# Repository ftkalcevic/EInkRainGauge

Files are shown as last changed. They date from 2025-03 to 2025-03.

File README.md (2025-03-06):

# Digital Rain Gauge with battery, solar panel and eink display

This project is a digital rain gauge that uses a tipping bucket mechanism to measure the amount of rain that has fallen. The rain gauge is powered by a battery and a solar panel and displays the amount of rain that has fallen on an eink display.

Note - the project details are not complete instructions.  I often uses scrap box parts, or parts I get from my local electronics store.  This is more of a guide to show what I did.

## Hardware

The hardware used in this project is as follows:

- STM32F103 microcontroller (initially developed with a blue pill board, then a custom board was created with only the required components).
- DFROBOT Micro Solar Power Manager / Charger with Regulated Output (DFR0579).
- Waveshare 250x122, 2.13inch E-Ink display HAT for Raspberry Pi (12915) - the one with the 8 pin connector.
- 500mAh LiPo battery.
- Reed switch to sense the rain bucket tipping.
- UV safe cover over the eink display (although the display faces away from the sun, it is unclear how the eink display works outside, so it is protected by a UV safe piece of perspex)

## Software

The files are in RainGaugeDigital.  I use VisualGDB hosted in Visual Studio.

The program spends most of its time in low power mode.  It will wake when the button tips (reed switch), or when one of the UI buttons is pressed.

The STM32F103 doesn't have any permanent storage, eg EEPROM.  The data collected is stored in ram.  If the battery is removed, the data is lost.

The display showing the mm of rain is not updated until 1 minute after the first tip.  This is to reduce power use.

The DFROBOT Micro Solar Power Manager can harvest very low voltages to charge the battery.  The built in voltage regulator powers the circuit at 3.3V.

The eink display code is based on the samples in the wiki.  A few changes were made to the code more flexible, and increase performance by using DMA transfers.

## Schematic

Files and a PDF schematic are in the EInkRainGaugePCB folder.  I use CircuitStudio.

## 3D Printed Parts

Alibre Design files are in the 3dModel\Alibre folder.  Step files in the 3dModel\Step folder.  Stl files in the 3dModel\Stl folder.

Note - not many fastners are shown in the 3D model.  I used M3 screws and heat set inserts.

The catchment funnel has 10 holes around the topmost edge to install 20cm 0.8mm spring steel (piano wire) pieces to discourage birds from perching on the funnel.

This is a 3d render of the model:
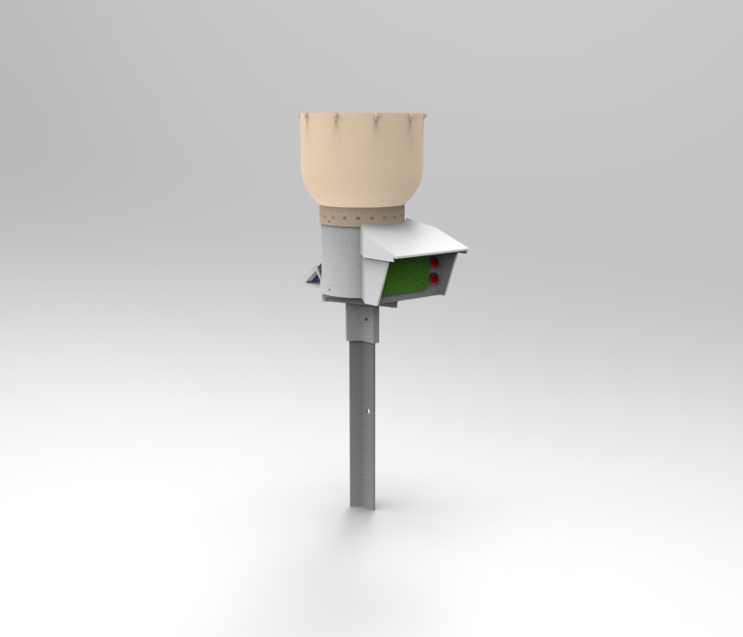
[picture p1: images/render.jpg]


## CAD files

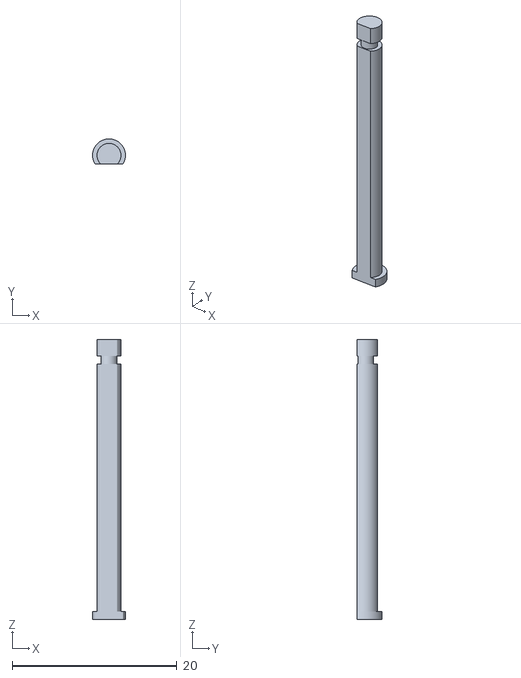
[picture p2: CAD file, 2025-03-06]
3dModel/stl/pin1.stl
4.00 x 3.06 x 34.0

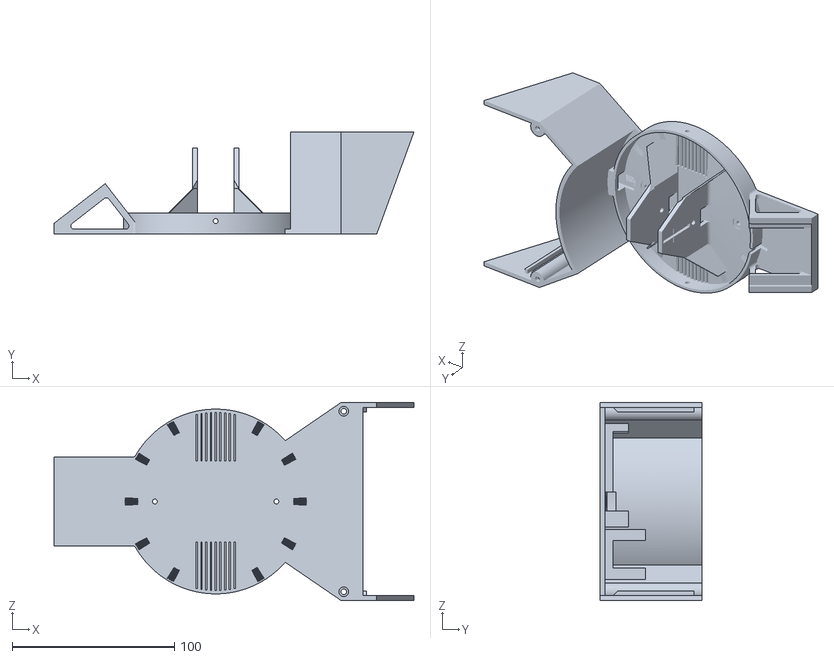
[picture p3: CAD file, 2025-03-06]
3dModel/stl/base.stl
222.2 x 63.0 x 122.2

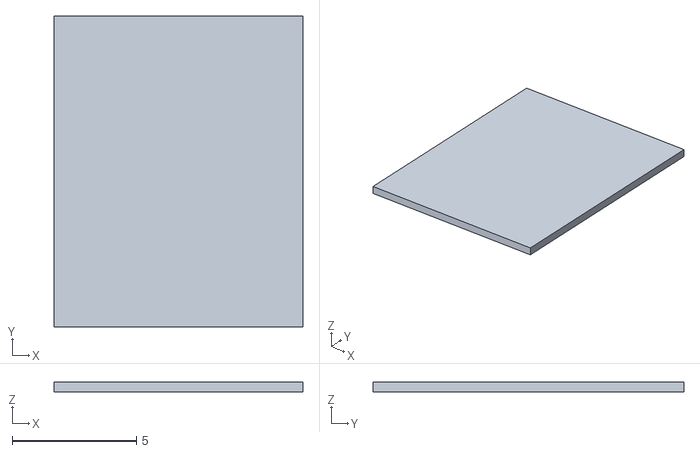
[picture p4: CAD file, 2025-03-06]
3dModel/stl/drip tab.stl
10.0 x 12.5 x 0.4

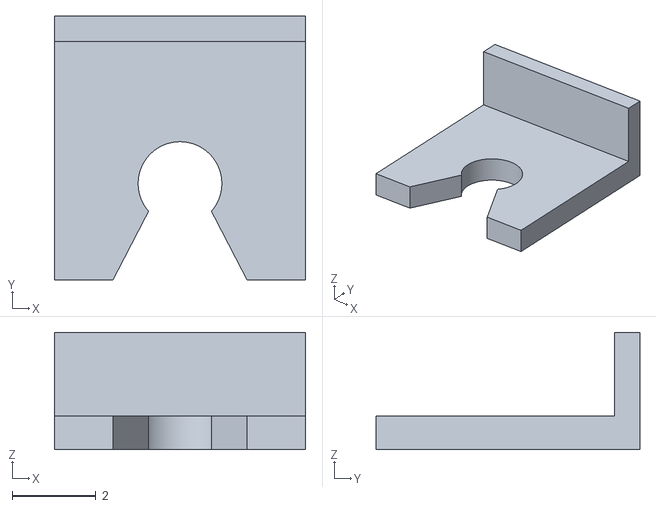
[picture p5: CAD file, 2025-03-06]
3dModel/stl/PinClip.stl
6.00 x 6.30 x 2.80

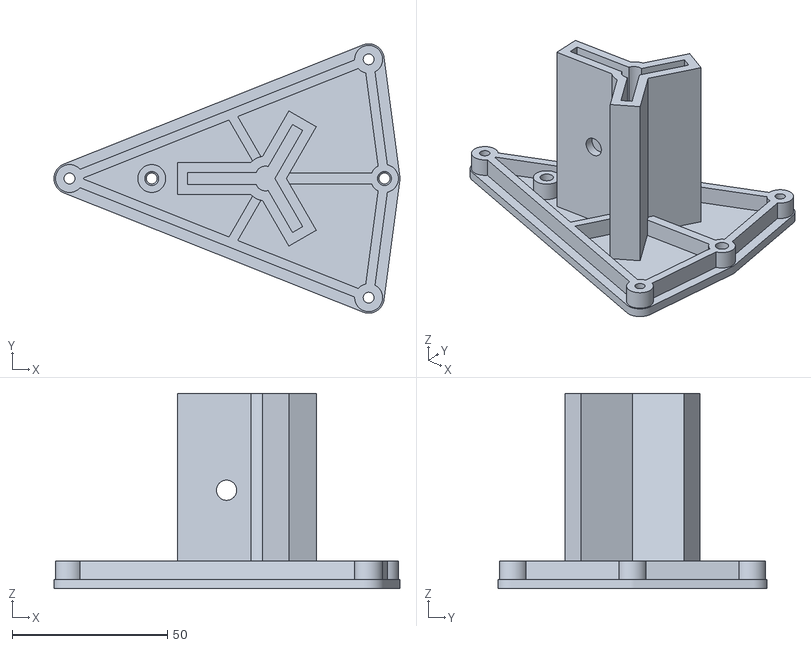
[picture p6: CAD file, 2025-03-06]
3dModel/stl/star picket leveling mount.stl
111.5 x 86.8 x 63.0

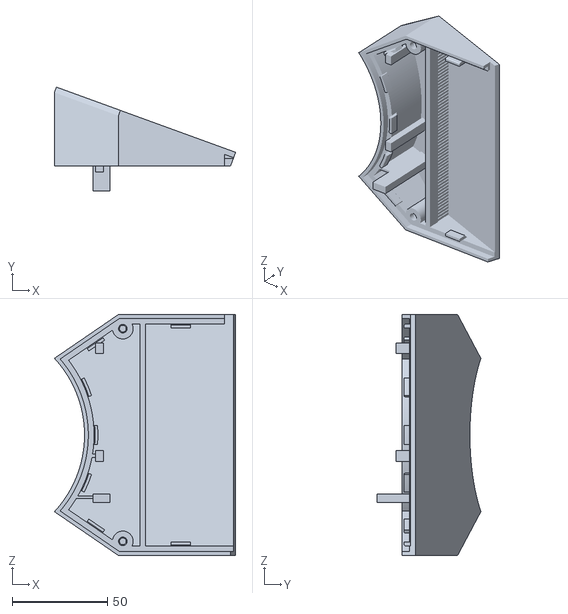
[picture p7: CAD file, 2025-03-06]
3dModel/stl/DisplayRoof.stl
94.9 x 54.4 x 126.2

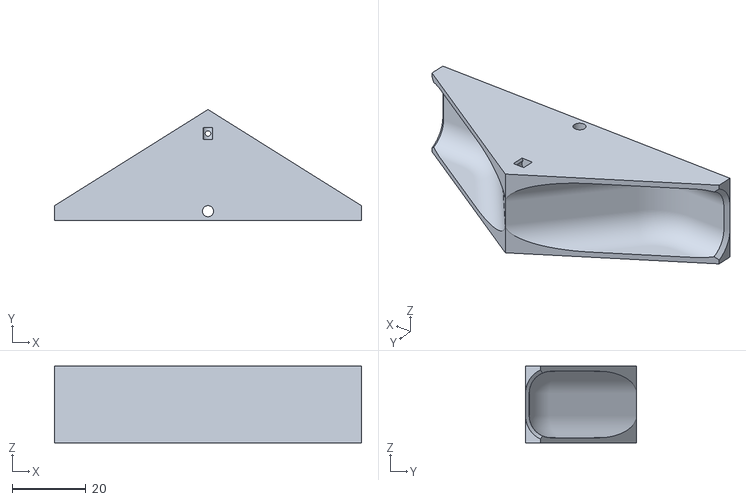
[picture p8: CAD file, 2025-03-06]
3dModel/stl/bucket2.stl
83.0 x 30.0 x 20.7

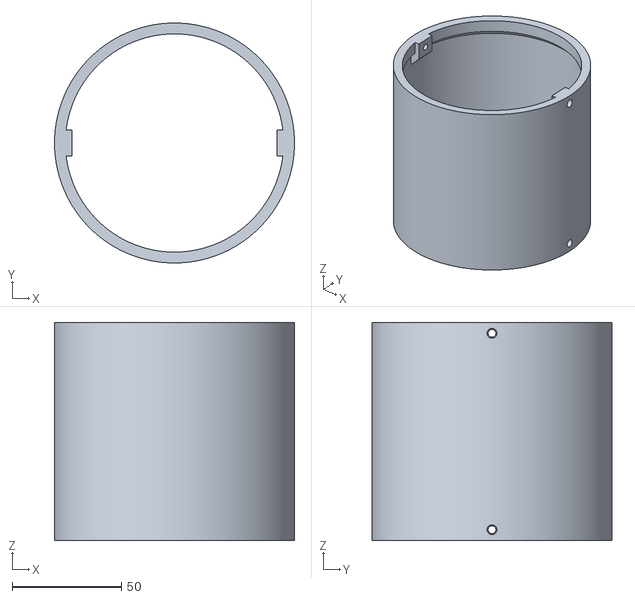
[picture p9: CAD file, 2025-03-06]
3dModel/stl/pipe.stl
110.0 x 110.0 x 100.0

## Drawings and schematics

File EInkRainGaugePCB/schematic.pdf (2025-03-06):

# P1 SWD RST SWDIO

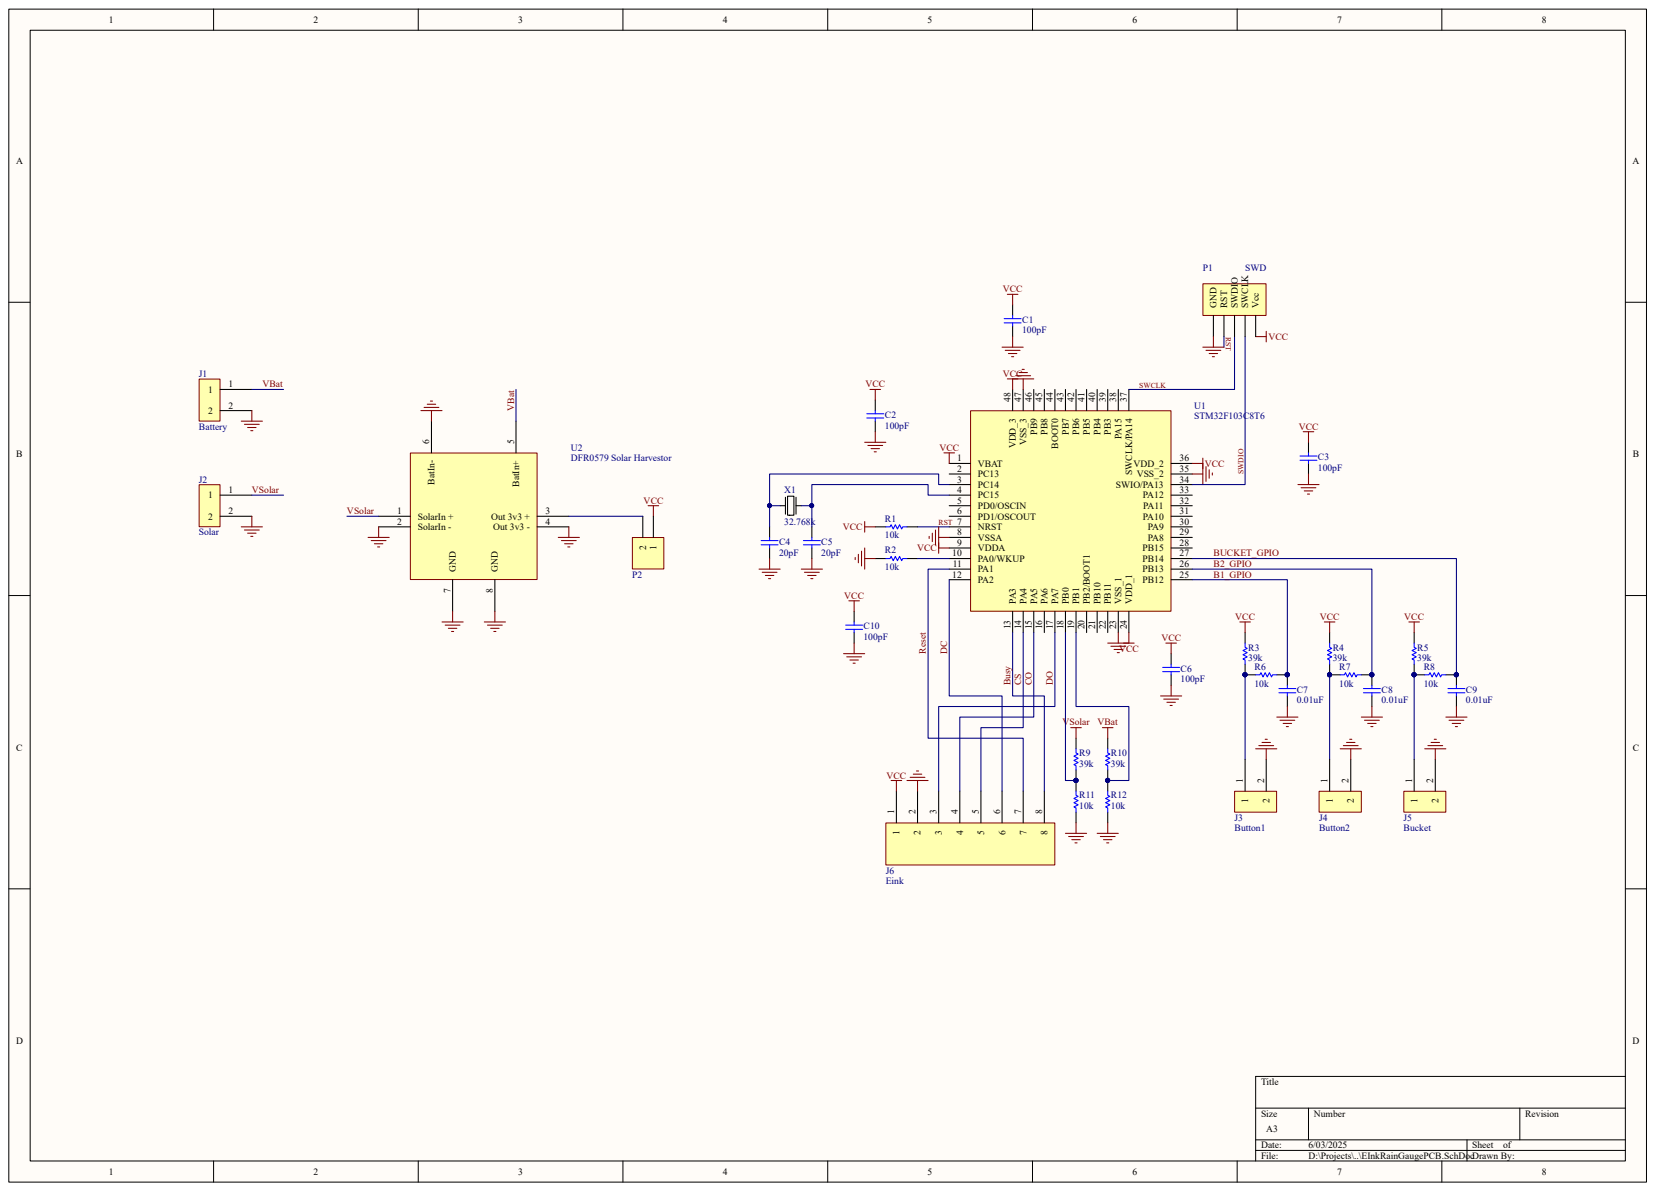
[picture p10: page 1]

VCC GND RST SWDIO SWCLK Vcc

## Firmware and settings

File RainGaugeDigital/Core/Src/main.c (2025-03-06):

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
/* Includes ------------------------------------------------------------------*/
#include "main.h"

/* USER CODE BEGIN Includes */
#include "../../RainGaugeApp.h"
#include <stdio.h>
#include "../../Debug.h"
/* USER CODE END Includes */

ADC_HandleTypeDef hadc1;

RTC_HandleTypeDef hrtc;

SPI_HandleTypeDef hspi1;
DMA_HandleTypeDef hdma_spi1_tx;

void SystemClock_Config(void);
static void MX_GPIO_Init(void);
static void MX_DMA_Init(void);
static void MX_ADC1_Init(void);
static void MX_RTC_Init(void);
static void MX_SPI1_Init(void);
/* USER CODE BEGIN 0 */
/// @brief  Possible STM32 system reset causes
typedef enum reset_cause_e
{
	RESET_CAUSE_UNKNOWN                    = 0,
	RESET_CAUSE_LOW_POWER_RESET,
	RESET_CAUSE_WINDOW_WATCHDOG_RESET,
	RESET_CAUSE_INDEPENDENT_WATCHDOG_RESET,
	RESET_CAUSE_SOFTWARE_RESET,
	RESET_CAUSE_POWER_ON_POWER_DOWN_RESET,
	RESET_CAUSE_EXTERNAL_RESET_PIN_RESET,
	RESET_CAUSE_BROWNOUT_RESET,
} reset_cause_t;

/// @brief      Obtain the STM32 system reset cause
/// @param      None
/// @return     The system reset cause
reset_cause_t reset_cause_get(void)
{
	reset_cause_t reset_cause;

	if (__HAL_RCC_GET_FLAG(RCC_FLAG_LPWRRST))
	{
		reset_cause = RESET_CAUSE_LOW_POWER_RESET;
	}
	else if (__HAL_RCC_GET_FLAG(RCC_FLAG_WWDGRST))
	{
		reset_cause = RESET_CAUSE_WINDOW_WATCHDOG_RESET;
	}
	else if (__HAL_RCC_GET_FLAG(RCC_FLAG_IWDGRST))
	{
		reset_cause = RESET_CAUSE_INDEPENDENT_WATCHDOG_RESET;
	}
	else if (__HAL_RCC_GET_FLAG(RCC_FLAG_SFTRST))
	{
		// This reset is induced by calling the ARM CMSIS 
		// `NVIC_SystemReset()` function!
		reset_cause = RESET_CAUSE_SOFTWARE_RESET; 
	}
	else if (__HAL_RCC_GET_FLAG(RCC_FLAG_PORRST))
	{
		reset_cause = RESET_CAUSE_POWER_ON_POWER_DOWN_RESET;
	}
	else if (__HAL_RCC_GET_FLAG(RCC_FLAG_PINRST))
	{
		reset_cause = RESET_CAUSE_EXTERNAL_RESET_PIN_RESET;
	}
	// Needs to come *after* checking the `RCC_FLAG_PORRST` flag in order to
	// ensure first that the reset cause is NOT a POR/PDR reset. See note
	// below. 
	//else if (__HAL_RCC_GET_FLAG(RCC_FLAG_BORRST))
	//{
	//	reset_cause = RESET_CAUSE_BROWNOUT_RESET;
	//}
	else
	{
		reset_cause = RESET_CAUSE_UNKNOWN;
	}

	// Clear all the reset flags or else they will remain set during future
	// resets until system power is fully removed.
	__HAL_RCC_CLEAR_RESET_FLAGS();

	return reset_cause; 
}

// Note: any of the STM32 Hardware Abstraction Layer (HAL) Reset and Clock
// Controller (RCC) header files, such as 
// "STM32Cube_FW_F7_V1.12.0/Drivers/STM32F7xx_HAL_Driver/Inc/stm32f7xx_hal_rcc.h",
// "STM32Cube_FW_F2_V1.7.0/Drivers/STM32F2xx_HAL_Driver/Inc/stm32f2xx_hal_rcc.h",
// etc., indicate that the brownout flag, `RCC_FLAG_BORRST`, will be set in
// the event of a "POR/PDR or BOR reset". This means that a Power-On Reset
// (POR), Power-Down Reset (PDR), OR Brownout Reset (BOR) will trip this flag.
// See the doxygen just above their definition for the 
// `__HAL_RCC_GET_FLAG()` macro to see this:
//      "@arg RCC_FLAG_BORRST: POR/PDR or BOR reset." <== indicates the Brownout
//      Reset flag will *also* be set in the event of a POR/PDR. 
// Therefore, you must check the Brownout Reset flag, `RCC_FLAG_BORRST`, *after*
// first checking the `RCC_FLAG_PORRST` flag in order to ensure first that the
// reset cause is NOT a POR/PDR reset.


/// @brief      Obtain the system reset cause as an ASCII-printable name string 
///             from a reset cause type
/// @param[in]  reset_cause     The previously-obtained system reset cause
/// @return     A null-terminated ASCII name string describing the system 
///             reset cause
const char * reset_cause_get_name(reset_cause_t reset_cause)
{
	const char * reset_cause_name = "TBD";

	switch (reset_cause)
	{
	case RESET_CAUSE_UNKNOWN:
		reset_cause_name = "UNKNOWN";
		break;
	case RESET_CAUSE_LOW_POWER_RESET:
		reset_cause_name = "LOW_POWER_RESET";
		break;
	case RESET_CAUSE_WINDOW_WATCHDOG_RESET:
		reset_cause_name = "WINDOW_WATCHDOG_RESET";
		break;
	case RESET_CAUSE_INDEPENDENT_WATCHDOG_RESET:
		reset_cause_name = "INDEPENDENT_WATCHDOG_RESET";
		break;
	case RESET_CAUSE_SOFTWARE_RESET:
		reset_cause_name = "SOFTWARE_RESET";
		break;
	case RESET_CAUSE_POWER_ON_POWER_DOWN_RESET:
		reset_cause_name = "POWER-ON_RESET (POR) / POWER-DOWN_RESET (PDR)";
		break;
	case RESET_CAUSE_EXTERNAL_RESET_PIN_RESET:
		reset_cause_name = "EXTERNAL_RESET_PIN_RESET";
		break;
	case RESET_CAUSE_BROWNOUT_RESET:
		reset_cause_name = "BROWNOUT_RESET (BOR)";
		break;
	}

	return reset_cause_name;
}
/* USER CODE END 0 */

/**
  * @brief  The application entry point.
  * @retval int
  */
int main(void)
{
  /* USER CODE BEGIN 1 */
  reset_cause_t reset_cause = reset_cause_get();
  /* USER CODE END 1 */

  /* MCU Configuration--------------------------------------------------------*/

  /* Reset of all peripherals, Initializes the Flash interface and the Systick. */
  HAL_Init();

  /* Configure the system clock */
  SystemClock_Config();

  /* Initialize all configured peripherals */
  MX_GPIO_Init();
  MX_DMA_Init();
  MX_ADC1_Init();
  MX_RTC_Init();
  MX_SPI1_Init();
  /* USER CODE BEGIN 2 */
#define SET_DATETIME_ON_START 
#ifdef SET_DATETIME_ON_START
	const uint8_t compileYear = (__DATE__[9] - '0') * 10 + (__DATE__[10] - '0');
	const uint8_t compileMonth = (__DATE__[0] == 'J') ? ((__DATE__[1] == 'a') ? 1 : ((__DATE__[2] == 'n') ? 6 : 7))    // Jan, Jun or Jul
										: (__DATE__[0] == 'F') ? 2                                                              // Feb
										: (__DATE__[0] == 'M') ? ((__DATE__[2] == 'r') ? 3 : 5)                                 // Mar or May
										: (__DATE__[0] == 'A') ? ((__DATE__[1] == 'p') ? 4 : 8)                                 // Apr or Aug
										: (__DATE__[0] == 'S') ? 9                                                              // Sep
										: (__DATE__[0] == 'O') ? 10                                                             // Oct
										: (__DATE__[0] == 'N') ? 11                                                             // Nov
										: (__DATE__[0] == 'D') ? 12                                                             // Dec
										: 0;
	const uint8_t compileDay = (__DATE__[4] == ' ') ? (__DATE__[5] - '0') : (__DATE__[4] - '0') * 10 + (__DATE__[5] - '0');
	
	const uint8_t compileHour = (__TIME__[0] == ' ') ? (__TIME__[1] - '0') : (__TIME__[0] - '0') * 10 + (__TIME__[1] - '0');
	const uint8_t compileMinute = (__TIME__[3] - '0') * 10 + (__TIME__[4] - '0');
	const uint8_t compileSecond = (__TIME__[6] - '0') * 10 + (__TIME__[7] - '0');

	RTC_TimeTypeDef time;
	time.Hours = compileHour;
	time.Minutes = compileMinute;
	time.Seconds = compileSecond;
	HAL_RTC_SetTime(&hrtc, &time, RTC_FORMAT_BIN);
	
	RTC_DateTypeDef date;
	date.Date = compileDay;
	date.Month = compileMonth;
	date.Year = compileYear;
	HAL_RTC_SetDate(&hrtc, &date, RTC_FORMAT_BIN);	 
#endif	
	{
		// EXTI configuration
		/*
		EXTI_HandleTypeDef hexti;
		HAL_EXTI_GetHandle(&hexti, EXTI_LINE_17);
		EXTI_ConfigTypeDef hexti_config;
		HAL_EXTI_GetConfigLine(&hexti, &hexti_config);
		HAL_EXTI_ClearPending(&hexti, EXTI_TRIGGER_RISING_FALLING);
		hexti_config.Line = EXTI_LINE_17;
		hexti_config.Mode = EXTI_MODE_INTERRUPT;
		hexti_config.Trigger = EXTI_TRIGGER_RISING;
		HAL_EXTI_SetConfigLine(&hexti, &hexti_config);
		*/
	}

  /* USER CODE END 2 */

  /* Infinite loop */
  /* USER CODE BEGIN WHILE */
  while (1)
  {
    /* USER CODE END WHILE */

    /* USER CODE BEGIN 3 */
	  Debug("The system reset cause is \"%s\"\n", reset_cause_get_name(reset_cause));
	  Debug("Delaying 5sec\n");
	  //HAL_Delay(5000);
	  Debug("Starting\n");
	  rain_guage_app();
  }
  /* USER CODE END 3 */
}

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


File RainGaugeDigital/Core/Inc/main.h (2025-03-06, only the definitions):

#define GPIO_EINK_Reset_Pin GPIO_PIN_1
#define GPIO_EINK_Reset_GPIO_Port GPIOA
#define GPIO_EINK_DC_Pin GPIO_PIN_2
#define GPIO_EINK_DC_GPIO_Port GPIOA
#define GPIO_EINK_Busy_Pin GPIO_PIN_3
#define GPIO_EINK_Busy_GPIO_Port GPIOA
#define SPI_EINK_CS_Pin GPIO_PIN_4
#define SPI_EINK_CS_GPIO_Port GPIOA
#define SPI_EINK_CO_Pin GPIO_PIN_5
#define SPI_EINK_CO_GPIO_Port GPIOA
#define SPI_EINK_DO_Pin GPIO_PIN_7
#define SPI_EINK_DO_GPIO_Port GPIOA
#define ADC1_VSOLAR_Pin GPIO_PIN_0
#define ADC1_VSOLAR_GPIO_Port GPIOB
#define ADC1_VBAT_Pin GPIO_PIN_1
#define ADC1_VBAT_GPIO_Port GPIOB
#define GPIO_BUTTON1_Pin GPIO_PIN_12
#define GPIO_BUTTON1_GPIO_Port GPIOB
#define GPIO_BUTTON1_EXTI_IRQn EXTI15_10_IRQn
#define GPIO_BUTTON2_Pin GPIO_PIN_13
#define GPIO_BUTTON2_GPIO_Port GPIOB
#define GPIO_BUTTON2_EXTI_IRQn EXTI15_10_IRQn
#define GPIO_BUCKET_Pin GPIO_PIN_14
#define GPIO_BUCKET_GPIO_Port GPIOB
#define GPIO_BUCKET_EXTI_IRQn EXTI15_10_IRQn
#define RST_GPIO_Port	GPIO_EINK_Reset_GPIO_Port
#define RST_Pin			GPIO_EINK_Reset_Pin
#define DC_GPIO_Port	GPIO_EINK_DC_GPIO_Port
#define DC_Pin			GPIO_EINK_DC_Pin
#define SPI_CS_GPIO_Port	SPI_EINK_CS_GPIO_Port
#define SPI_CS_Pin		SPI_EINK_CS_Pin
#define BUSY_GPIO_Port	GPIO_EINK_Busy_GPIO_Port
#define BUSY_Pin		GPIO_EINK_Busy_Pin
#define DIN_GPIO_Port	SPI_EINK_DO_GPIO_Port
#define DIN_Pin			SPI_EINK_DO_Pin
#define SCK_GPIO_Port	SPI_EINK_CO_GPIO_Port
#define SCK_Pin			SPI_EINK_CO_Pin

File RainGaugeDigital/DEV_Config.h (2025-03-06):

/*****************************************************************************
* | File      	:   DEV_Config.h
* | Author      :   Waveshare team
* | Function    :   Hardware underlying interface
* | Info        :
*                Used to shield the underlying layers of each master 
*                and enhance portability
*----------------
* |	This version:   V2.0
* | Date        :   2018-10-30
* | Info        :
* 1.add:
*   UBYTE\UWORD\UDOUBLE
* 2.Change:
*   EPD_RST -> EPD_RST_PIN
*   EPD_DC -> EPD_DC_PIN
*   EPD_CS -> EPD_CS_PIN
*   EPD_BUSY -> EPD_BUSY_PIN
* 3.Remote:
*   EPD_RST_1\EPD_RST_0
*   EPD_DC_1\EPD_DC_0
*   EPD_CS_1\EPD_CS_0
*   EPD_BUSY_1\EPD_BUSY_0
* 3.add:
*   #define DEV_Digital_Write(_pin, _value) bcm2835_gpio_write(_pin, _value)
*   #define DEV_Digital_Read(_pin) bcm2835_gpio_lev(_pin)
*   #define DEV_SPI_WriteByte(__value) bcm2835_spi_transfer(__value)
#
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
******************************************************************************/
#ifndef _DEV_CONFIG_H_
#define _DEV_CONFIG_H_

#include "main.h"
#include "stm32f1xx_hal.h"
#include "stm32f1xx_hal_gpio.h"
#include <stdint.h>
#include <stdio.h>

/**
 * data
**/
#define UBYTE   uint8_t
#define UWORD   uint16_t
#define UDOUBLE uint32_t

/**
 * e-Paper GPIO
**/
#define EPD_RST_PIN     RST_GPIO_Port, RST_Pin
#define EPD_DC_PIN      DC_GPIO_Port, DC_Pin
#define EPD_PWR_PIN     PWR_GPIO_Port, PWR_Pin
#define EPD_CS_PIN      SPI_CS_GPIO_Port, SPI_CS_Pin
#define EPD_BUSY_PIN    BUSY_GPIO_Port, BUSY_Pin
#define EPD_MOSI_PIN    DIN_GPIO_Port, DIN_Pin
#define EPD_SCLK_PIN    SCK_GPIO_Port, SCK_Pin

/**
 * GPIO read and write
**/
#define DEV_Digital_Write(_pin, _value) HAL_GPIO_WritePin(_pin, _value == 0? GPIO_PIN_RESET:GPIO_PIN_SET)
#define DEV_Digital_Read(_pin) HAL_GPIO_ReadPin(_pin)

/**
 * delay x ms
**/
#define DEV_Delay_ms(__xms) HAL_Delay(__xms);

void DEV_SPI_WriteByte(UBYTE value);
void DEV_SPI_Write_nByte(uint8_t *value, uint16_t len);

int DEV_Module_Init(void);
void DEV_Module_Exit(void);
void DEV_GPIO_Init(void);
void DEV_SPI_Init(void);
void DEV_SPI_SendData(UBYTE Reg);
UBYTE DEV_SPI_ReadData(void);
#endif

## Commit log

2025-03-06 Initial code commit
    [EInkRainGaugePCB.PrjPcb, EInkRainGaugePCB.SchDoc]
2025-03-06 Add readme. Add 3d model. Add schematic.
    [DisplayRoof.stl, EInkRainGaugePCB.PrjPcb, EInkRainGaugePCB.SchDoc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]

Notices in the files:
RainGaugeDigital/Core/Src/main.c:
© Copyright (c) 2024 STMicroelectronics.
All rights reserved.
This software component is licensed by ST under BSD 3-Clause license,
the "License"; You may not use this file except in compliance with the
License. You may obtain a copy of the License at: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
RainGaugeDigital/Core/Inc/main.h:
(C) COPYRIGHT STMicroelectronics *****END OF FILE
